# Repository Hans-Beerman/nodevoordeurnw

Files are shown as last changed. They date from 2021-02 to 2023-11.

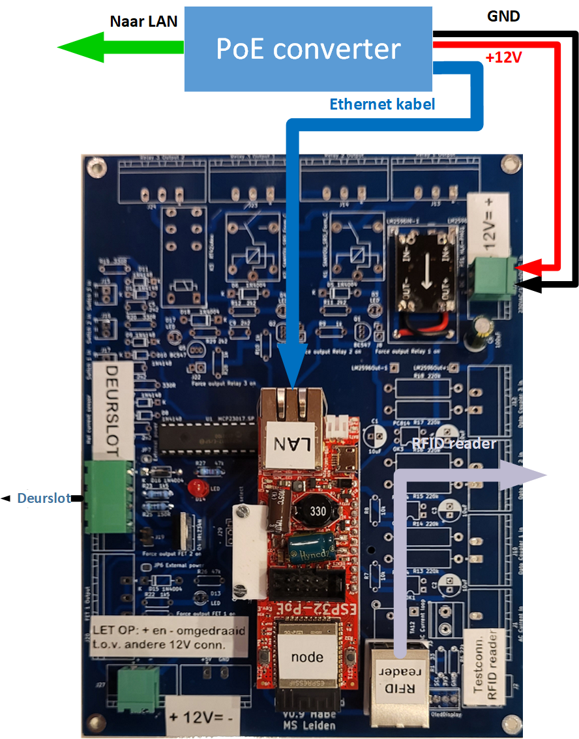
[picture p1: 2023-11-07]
Drawings/Aansluitschema print NodeVoordeur V0.9-2 20231104.png

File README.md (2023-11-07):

**NodeVoordeur**

NodeVoordeur is a node, used at the MakerSpace Leiden, to control the front door of the Makerspace. This repository has the following subdirs:

- **3D designs:**

The drawings of 3D parts, which are used on the PCB

- **Drawings:**

Schematic of the wiring between the different modules used

- **KiCad\_files:**

The design of the PCB used for the Node/Controller.

- **Photos:**

Some photos of the Node made.

- **PlatformIO\_Files:**

The source code for the Node. For the development of this software PlatformIO is used, an Extension on Visual Studio Code.

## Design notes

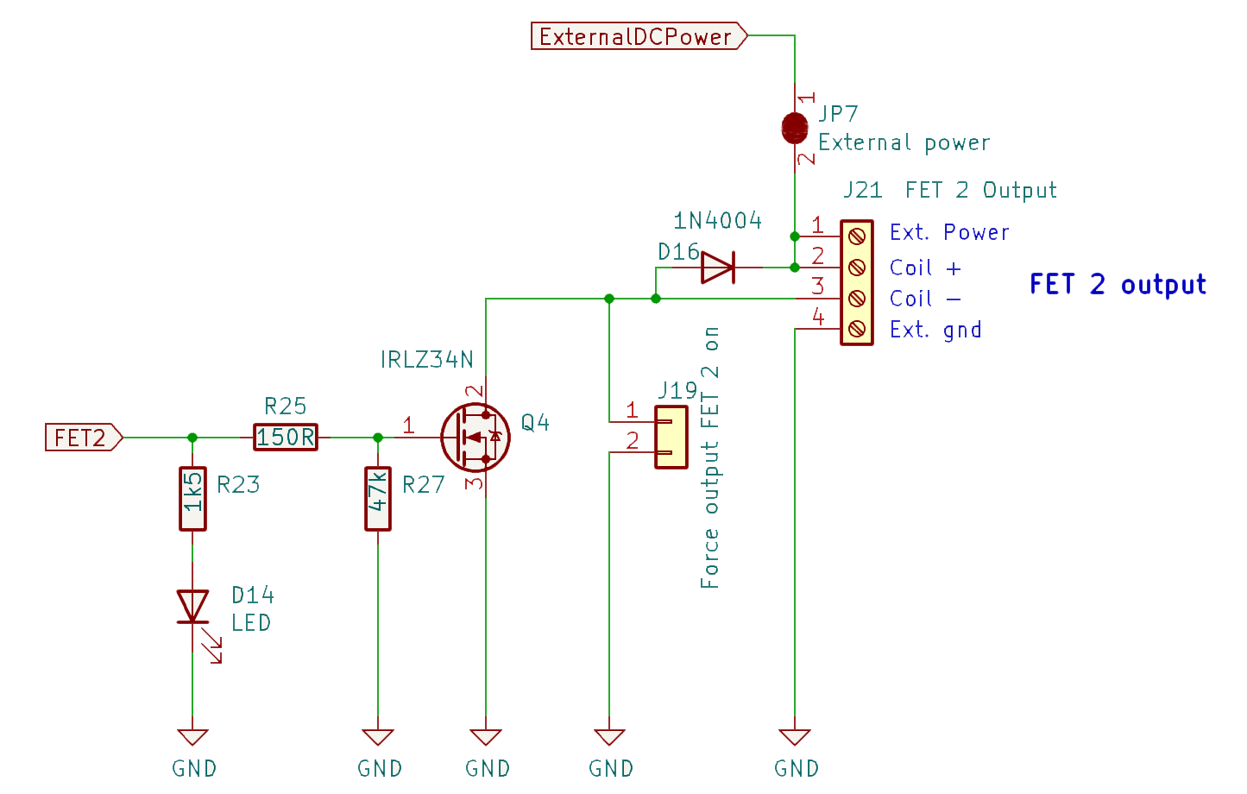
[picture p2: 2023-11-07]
Drawings/FET2 aansluiting deurslot.png

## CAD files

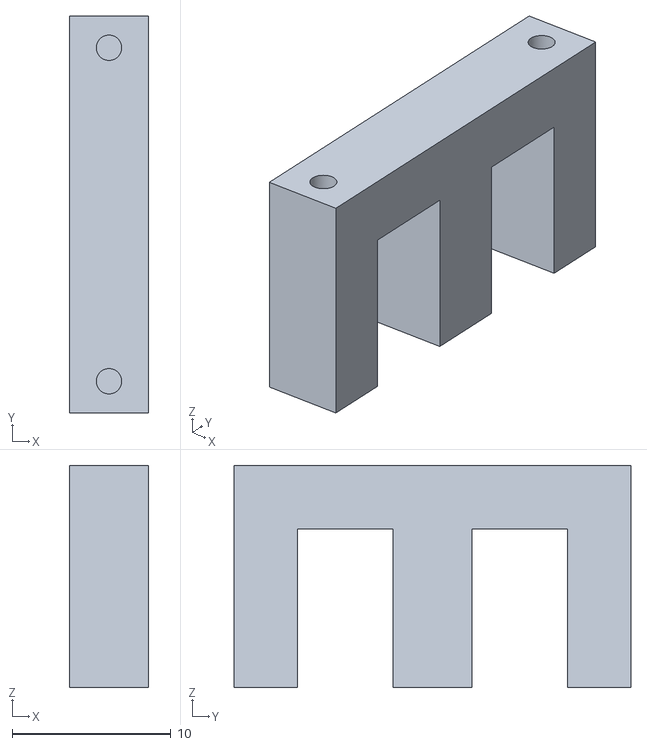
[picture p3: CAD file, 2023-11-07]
3D designs/stl files/Clip ESP32 onderkant.stl
5.00 x 25.0 x 14.0

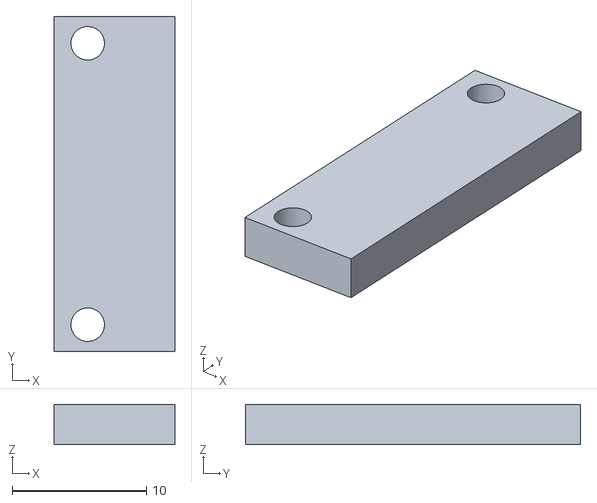
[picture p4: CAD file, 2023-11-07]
3D designs/stl files/Clip ESP32 bovenkant.stl
9.00 x 25.0 x 3.00

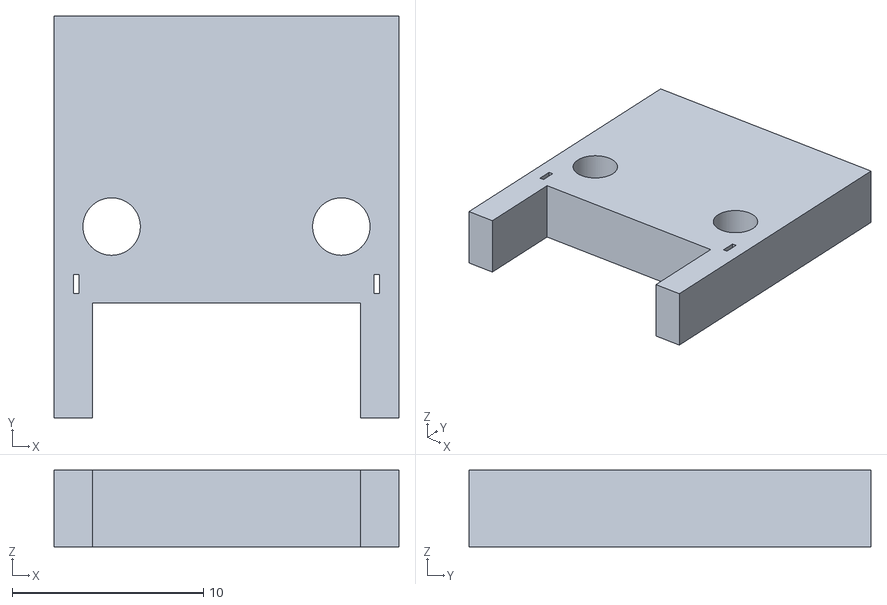
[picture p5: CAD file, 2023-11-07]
3D designs/stl files/Onderlegplaatje RJ45 female connector.stl
18.0 x 21.0 x 4.00

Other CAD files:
3D designs/Fusion 360 files/Clip ESP32 v4.f3d
3D designs/Fusion 360 files/Onderlegplaatje RJ45 female connector v1.f3d

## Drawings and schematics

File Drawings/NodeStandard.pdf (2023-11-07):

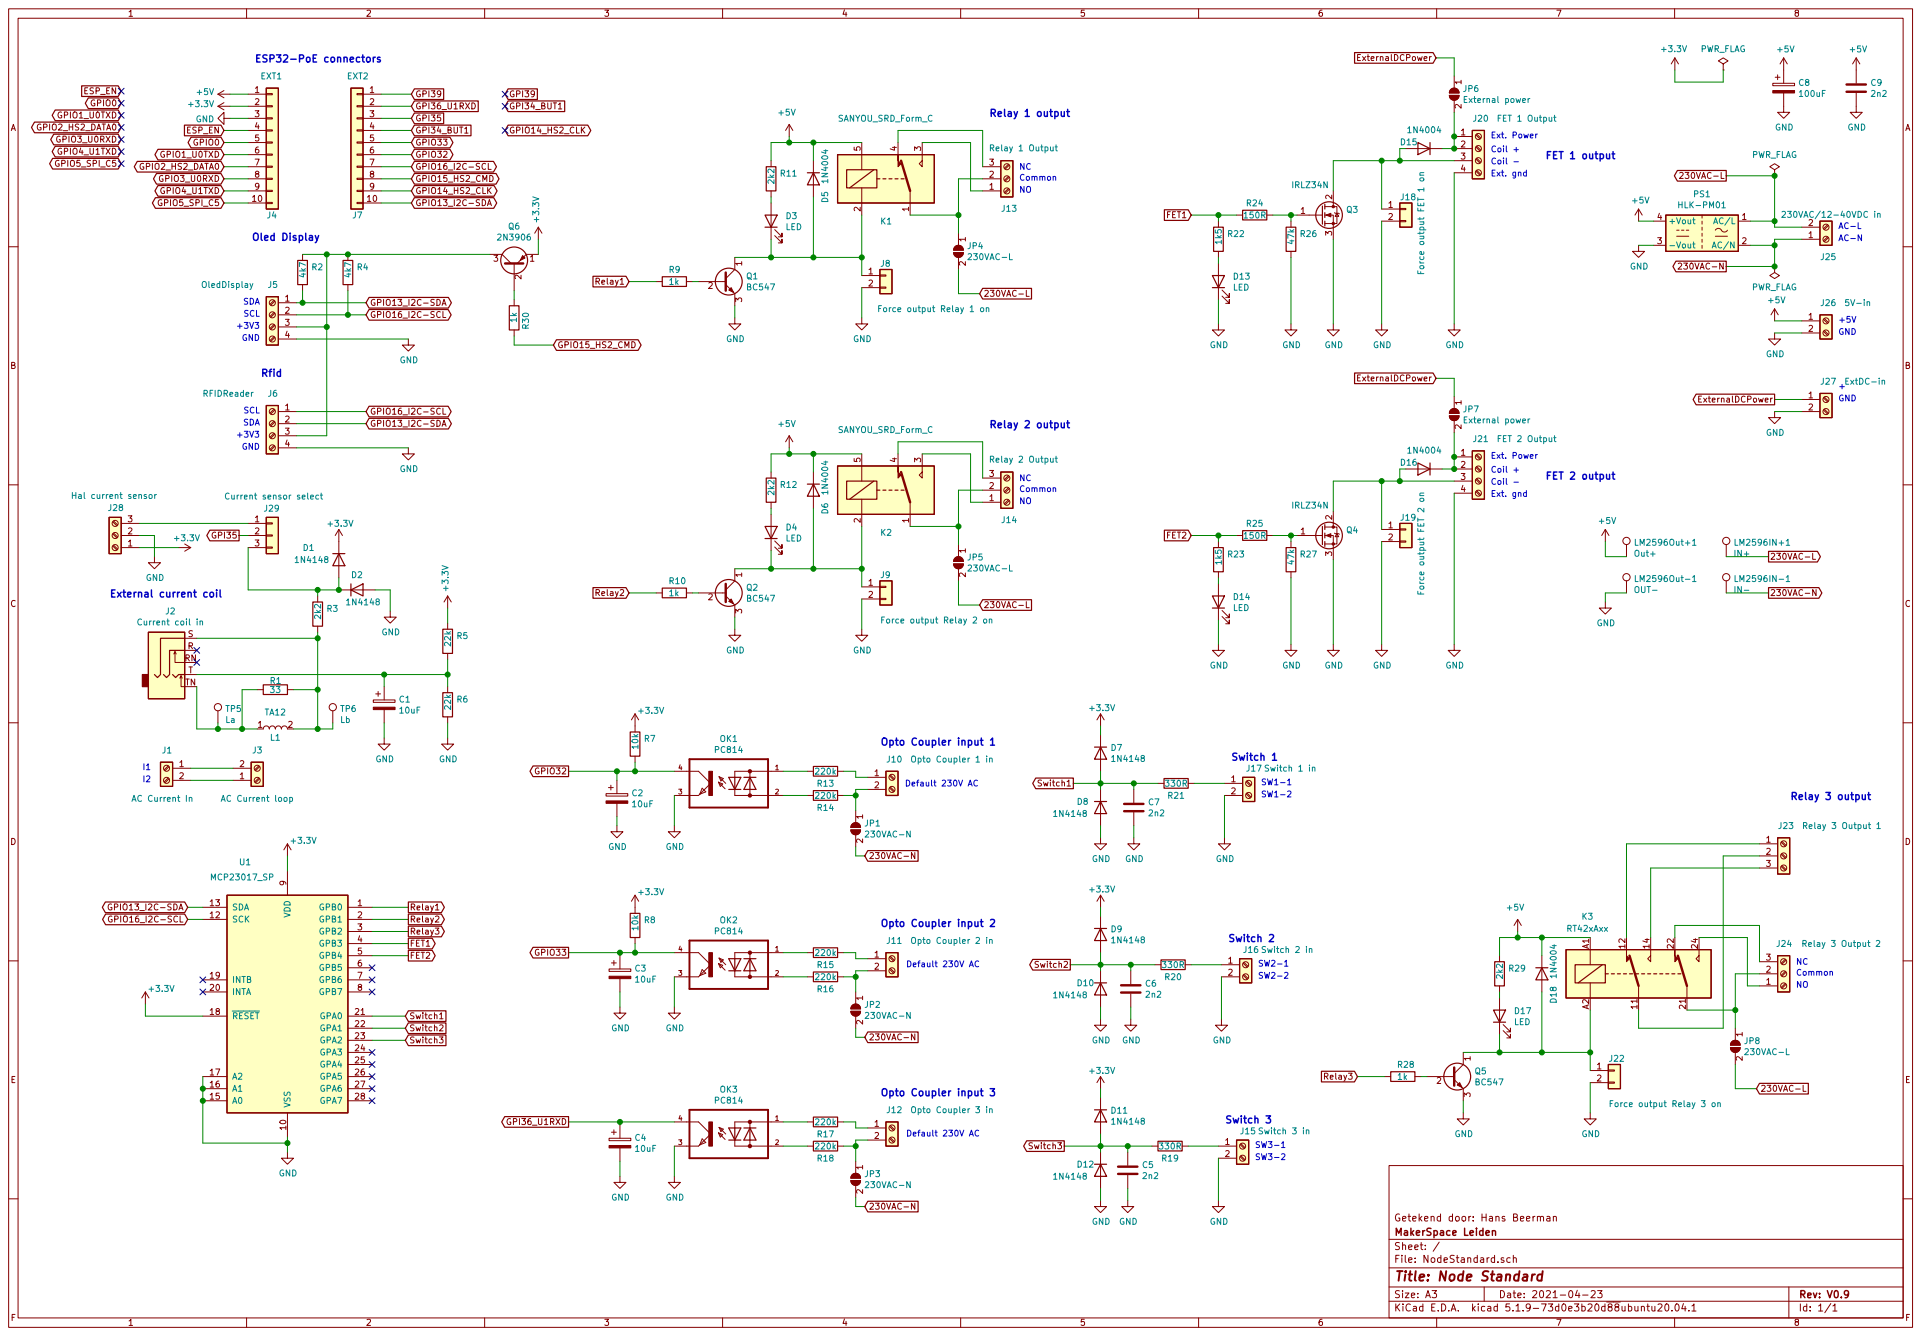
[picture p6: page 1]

1/2 J18 Force output FET 1 on D15

File: NodeStandard.sch Sheet: / MakerSpace Leiden Getekend door: Hans Beerman

Id: 1/1 Title: Node Standard

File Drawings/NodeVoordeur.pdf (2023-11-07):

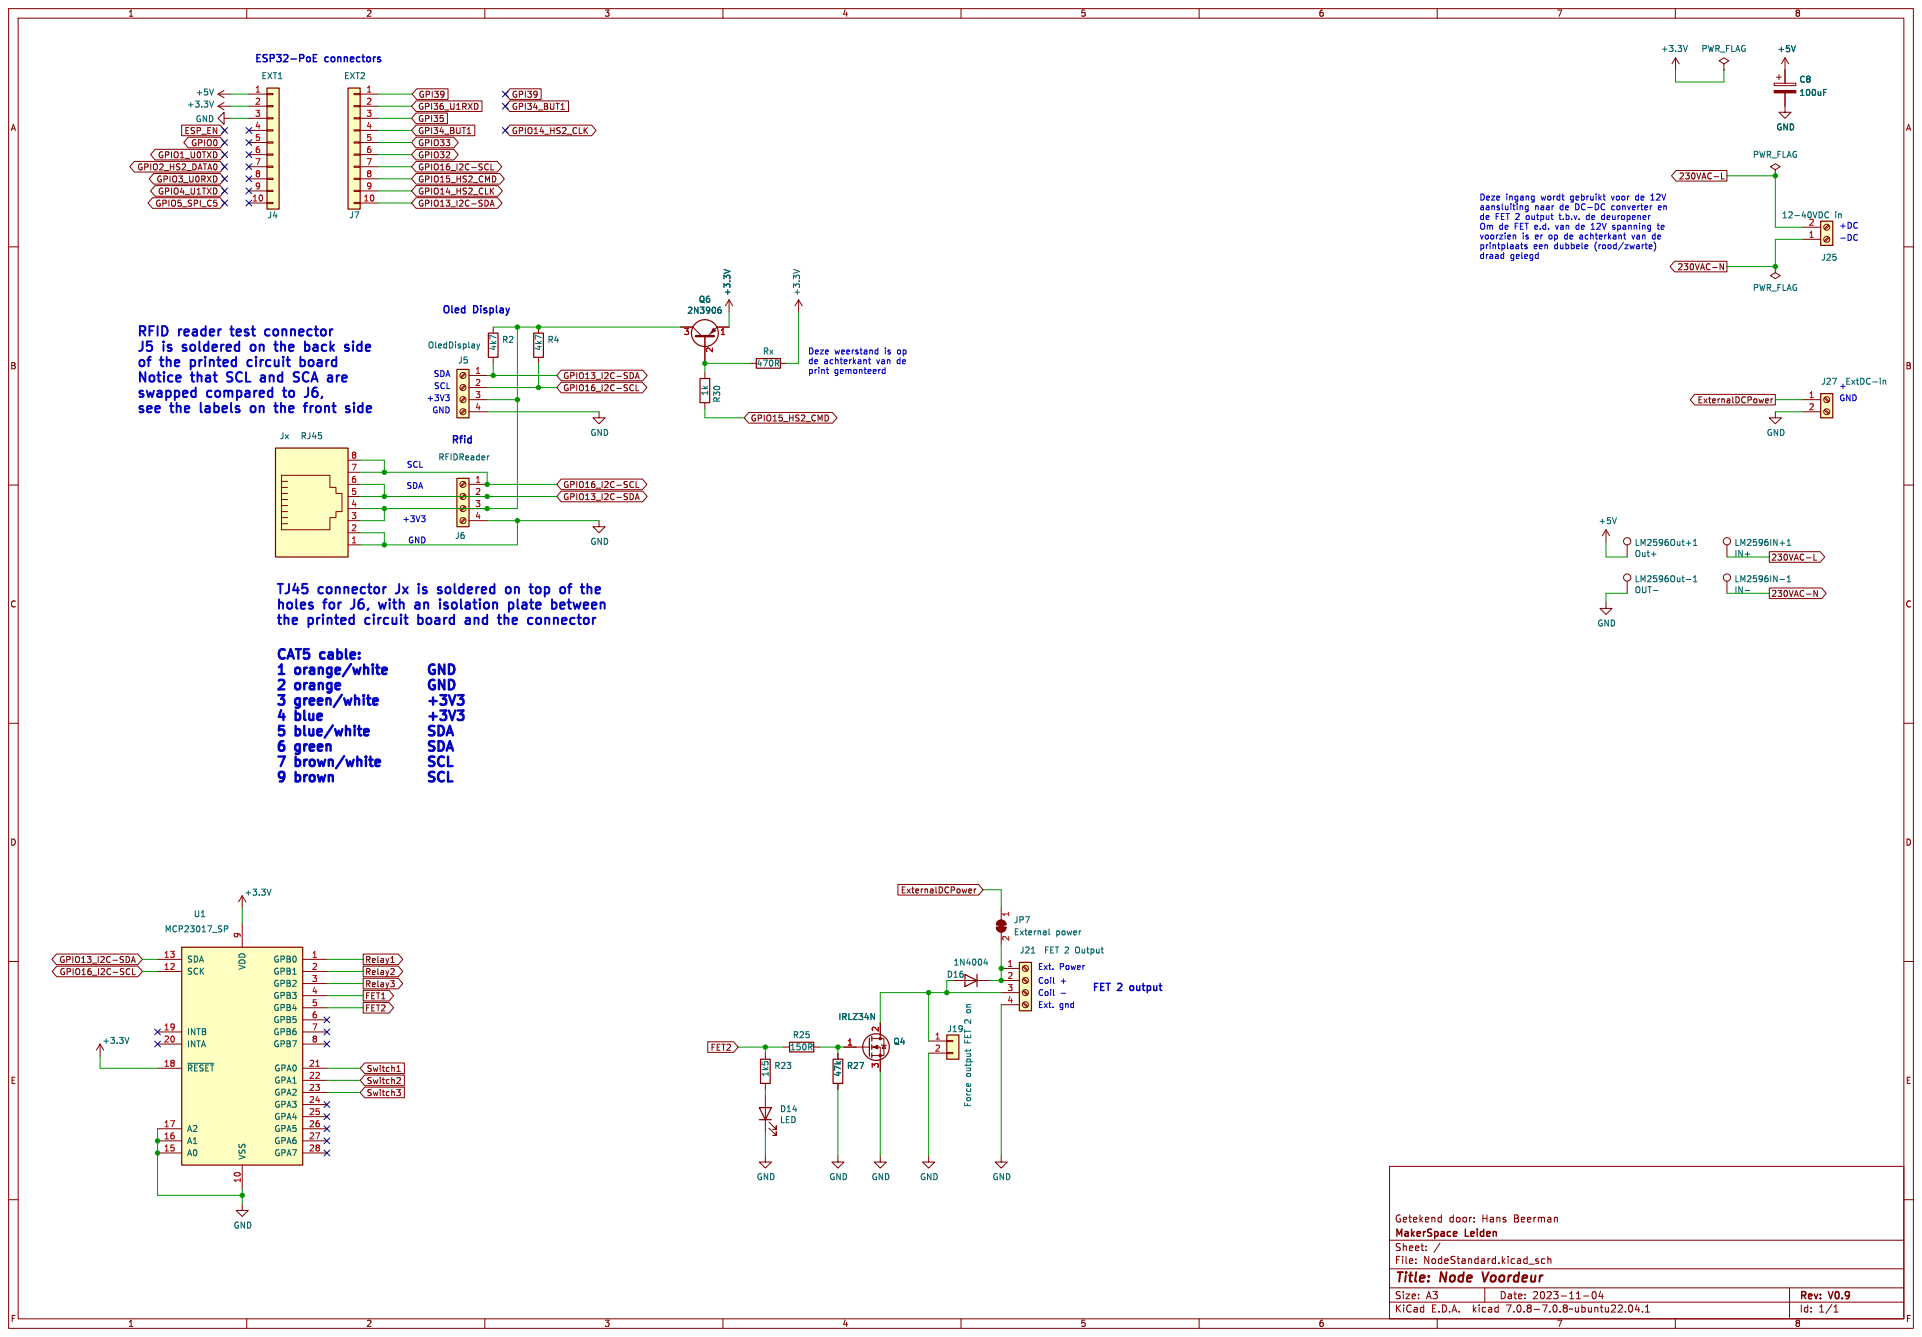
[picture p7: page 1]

J5 is soldered on the back side
of the printed circuit board
Notice that SCL and SCA are
swapped compared to J6, see the labels on the front side

TJ45 connector Jx is soldered on top of the
holes for J6, with an isolation plate between

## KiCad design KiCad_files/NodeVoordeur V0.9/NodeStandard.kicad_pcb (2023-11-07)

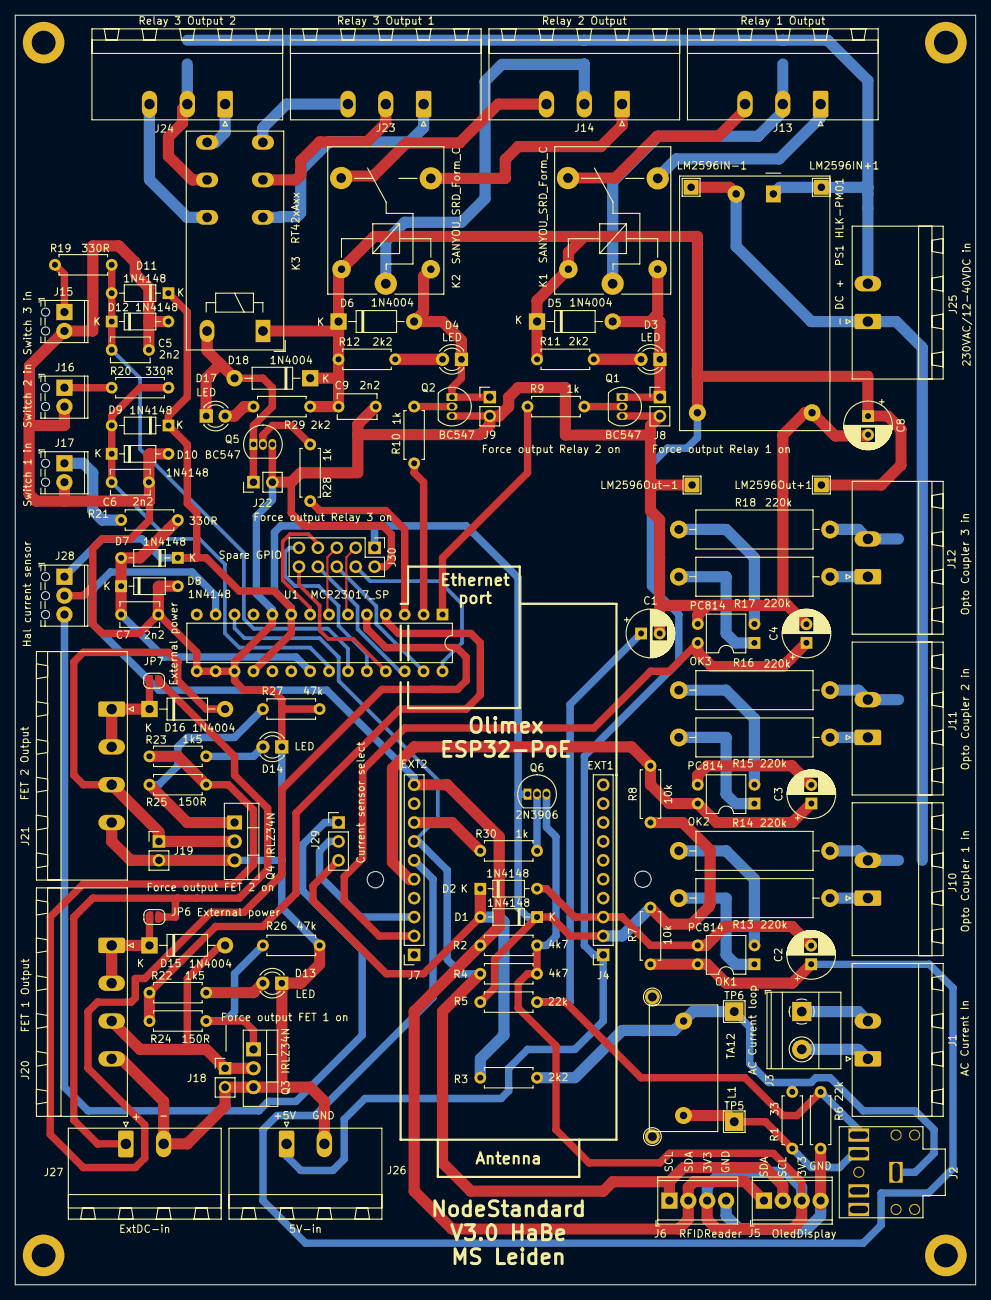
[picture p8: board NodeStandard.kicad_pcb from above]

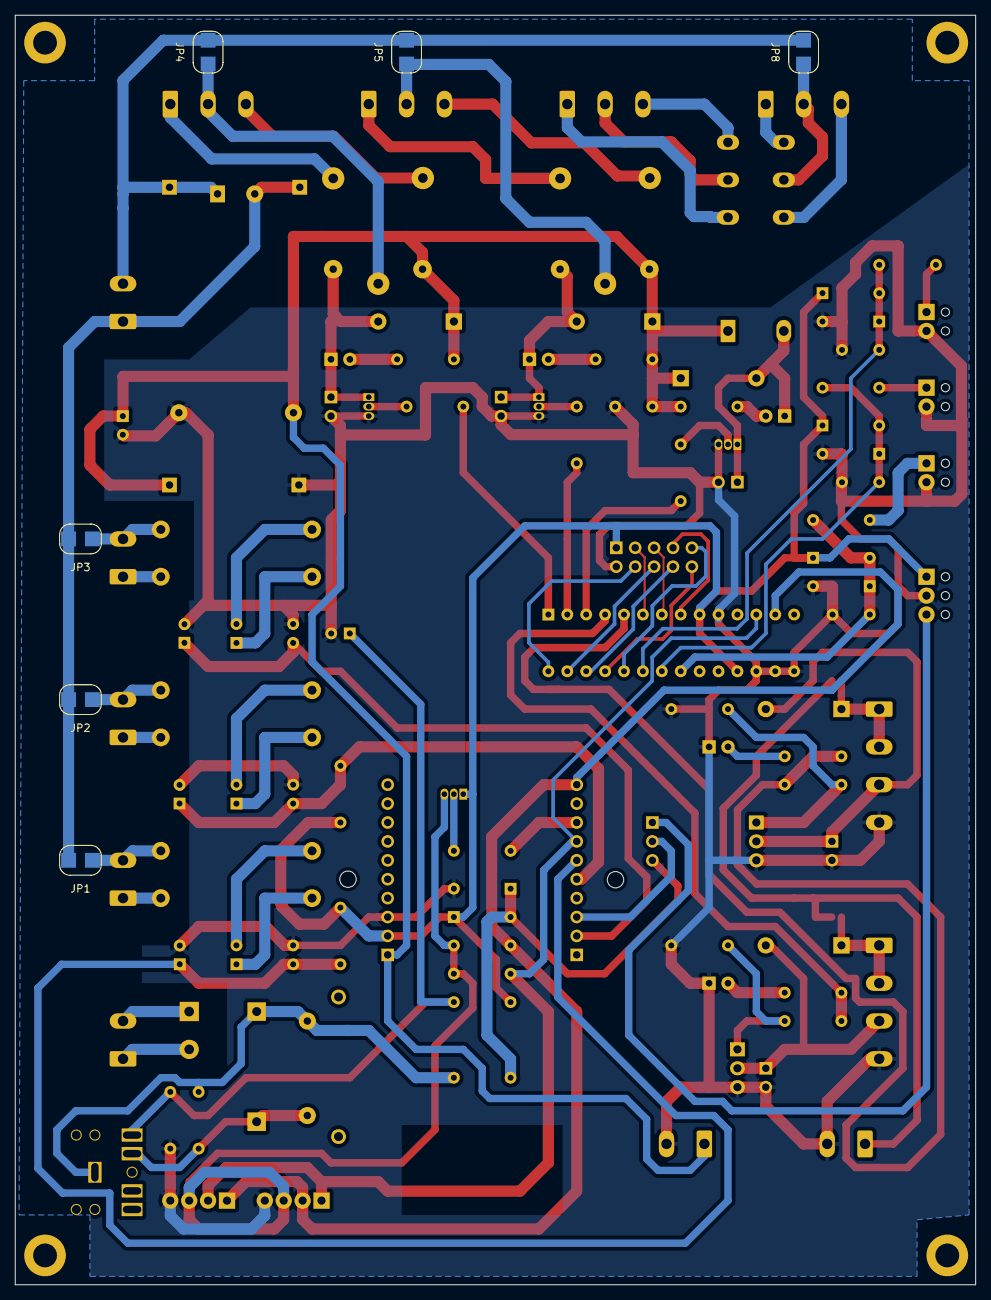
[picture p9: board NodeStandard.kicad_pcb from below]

Board: 2 copper layers, 129.0 x 170.6 mm, 116 parts (6 on the bottom side), 82 nets.

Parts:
C1, C2, C3, C4: 10uF; CP_Radial_D6.3mm_P2.50mm
C5, C6, C7, C9: 2n2; C_Disc_D5.1mm_W3.2mm_P5.00mm
C8: 100uF; CP_Radial_D6.3mm_P2.50mm
D1, D2, D7, D8, D9, D10, D11, D12: 1N4148; D_DO-35_SOD27_P7.62mm_Horizontal
D3, D4, D13, D14, D17: LED; LED_D3.0mm
D5, D6, D15, D16, D18: 1N4004; D_DO-41_SOD81_P10.16mm_Horizontal
J1: AC Current In; PhoenixContact_MSTB_2,5_2-GF-5,08_1x02_P5.08mm_Horizontal_T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
J2: Current coil in; Jack_3.5mm_CUI_FEMPM_Horizontal
J3: AC Current loop; TerminalBlock_Phoenix_MKDS-1,5-2-5.08_1x02_P5.08mm_Horizont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
J4: EXT1; PinSocket_1x10_P2.54mm_Vertical
J5: OledDisplay; TerminalBlock_Phoenix_MPT-0,5-4-2.54_1x04_P2.54mm_Horizontal
J6: RFIDReader; TerminalBlock_Phoenix_MPT-0,5-4-2.54_1x04_P2.54mm_Horizontal
J7: EXT2; PinSocket_1x10_P2.54mm_Vertical
J8: Force output Relay 1 on; PinHeader_1x02_P2.54mm_Vertical
J9: Force output Relay 2 on; PinHeader_1x02_P2.54mm_Vertical
J10: Opto Coupler 1 in; PhoenixContact_MSTB_2,5_2-GF-5,08_1x02_P5.08mm_Horizontal_T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
J11: Opto Coupler 2 in; PhoenixContact_MSTB_2,5_2-GF-5,08_1x02_P5.08mm_Horizontal_T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
J12: Opto Coupler 3 in; PhoenixContact_MSTB_2,5_2-GF-5,08_1x02_P5.08mm_Horizontal_T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
J13: Relay 1 Output; PhoenixContact_MSTB_2,5_3-GF-5,08_1x03_P5.08mm_Horizontal_T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
J14: Relay 2 Output; PhoenixContact_MSTB_2,5_3-GF-5,08_1x03_P5.08mm_Horizontal_T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
J15: Switch 3 in; TerminalBlock_Phoenix_MPT-0,5-2-2.54_1x02_P2.54mm_Horizontal
J16: Switch 2 in; TerminalBlock_Phoenix_MPT-0,5-2-2.54_1x02_P2.54mm_Horizontal
J17: Switch 1 in; TerminalBlock_Phoenix_MPT-0,5-2-2.54_1x02_P2.54mm_Horizontal
J18: Force output FET 1 on; PinHeader_1x02_P2.54mm_Vertical
J19: Force output FET 2 on; PinHeader_1x02_P2.54mm_Vertical
J20: FET 1 Output; PhoenixContact_MSTB_2,5_4-GF-5,08_1x04_P5.08mm_Horizontal_T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
J21: FET 2 Output; PhoenixContact_MSTB_2,5_4-GF-5,08_1x04_P5.08mm_Horizontal_T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
J22: Force output Relay 3 on; PinHeader_1x02_P2.54mm_Vertical
J23: Relay 3 Output 1; PhoenixContact_MSTB_2,5_3-GF-5,08_1x03_P5.08mm_Horizontal_T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
J24: Relay 3 Output 2; PhoenixContact_MSTB_2,5_3-GF-5,08_1x03_P5.08mm_Horizontal_T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
J25: 230VAC/12-40VDC in; PhoenixContact_MSTB_2,5_2-GF-5,08_1x02_P5.08mm_Horizontal_T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
J26: 5V-in; PhoenixContact_MSTB_2,5_2-GF-5,08_1x02_P5.08mm_Horizontal_T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
J27: ExtDC-in; PhoenixContact_MSTB_2,5_2-GF-5,08_1x02_P5.08mm_Horizontal_T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
J28: Hal current sensor; TerminalBlock_Phoenix_MPT-0,5-3-2.54_1x03_P2.54mm_Horizontal
J29: Current sensor select; PinHeader_1x03_P2.54mm_Vertical
J30: Spare GPIO; PinHeader_2x05_P2.54mm_Vertical
JP1, JP2, JP3: 230VAC-N; SolderJumper-2_P3mm_Open_RoundedPad
JP4, JP5, JP8: 230VAC-L; SolderJumper-2_P3mm_Open_RoundedPad
JP6, JP7: External power; SolderJumper-2_P1.3mm_Open_RoundedPad1.0x1.5mm
K1, K2: SANYOU_SRD_Form_C; Relay_SPDT_SANYOU_SRD_Series_Form_C
K3: RT42xAxx; Relay_DPDT_Schrack-RT2-FormC_RM5mm
L1: TA12; TA12-100
LM2596IN+1: IN+; TestPoint_THTPad_2.0x2.0mm_Drill1.0mm
LM2596IN-1: IN-; TestPoint_THTPad_2.0x2.0mm_Drill1.0mm
LM2596Out+1: Out+; TestPoint_THTPad_2.0x2.0mm_Drill1.0mm
LM2596Out-1: OUT-; TestPoint_THTPad_2.0x2.0mm_Drill1.0mm
OK1, OK2, OK3: PC814; DIP-4_W7.62mm
PS1: HLK-PM01; Converter_ACDC_HiLink_HLK-PMxx
Q1, Q2, Q5: BC547; TO-92_Inline
Q3, Q4: IRLZ34N; TO-220-3_Vertical
Q6: 2N3906; TO-92_Inline
R1: 33; R_Axial_DIN0207_L6.3mm_D2.5mm_P7.62mm_Horizontal
R2, R4: 4k7; R_Axial_DIN0207_L6.3mm_D2.5mm_P7.62mm_Horizontal
R3, R11, R12, R29: 2k2; R_Axial_DIN0207_L6.3mm_D2.5mm_P7.62mm_Horizontal
R5, R6: 22k; R_Axial_DIN0207_L6.3mm_D2.5mm_P7.62mm_Horizontal
R7, R8: 10k; R_Axial_DIN0207_L6.3mm_D2.5mm_P7.62mm_Horizontal
R9, R10, R28, R30: 1k; R_Axial_DIN0207_L6.3mm_D2.5mm_P7.62mm_Horizontal
R13, R14, R15, R16, R17, R18: 220k; R_Axial_DIN0516_L15.5mm_D5.0mm_P20.32mm_Horizontal
R19, R20, R21: 330R; R_Axial_DIN0207_L6.3mm_D2.5mm_P7.62mm_Horizontal
R22, R23: 1k5; R_Axial_DIN0207_L6.3mm_D2.5mm_P7.62mm_Horizontal
R24, R25: 150R; R_Axial_DIN0207_L6.3mm_D2.5mm_P7.62mm_Horizontal
R26, R27: 47k; R_Axial_DIN0207_L6.3mm_D2.5mm_P7.62mm_Horizontal
TP5: La; TestPoint_THTPad_2.5x2.5mm_Drill1.2mm
TP6: Lb; TestPoint_THTPad_2.5x2.5mm_Drill1.2mm
U1: MCP23017_SP; DIP-28_W7.62mm

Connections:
230VAC-L: J25.2, JP4.2 (B), JP5.2 (B), JP8.2 (B), LM2596IN+1.1, PS1.1 (AC/L)
230VAC-N: J25.1, JP1.2 (B), JP2.2 (B), JP3.2 (B), LM2596IN-1.1, PS1.2 (AC/N)
+3V3: D1.1 (K), D7.1 (K), D9.1 (K), D11.1 (K), J4.2, J28.1, J30.1, Q6.1 (E), R5.1, R7.1, R8.1, U1.9 (VDD), U1.18 (~RESET)
+5V: C8.1, C9.1, D5.1 (K), D6.1 (K), D18.1 (K), J4.1, J26.1, K1.5, K2.5, K3.A1, LM2596Out+1.1, PS1.4 (+Vout), R11.1, R12.1, R29.1
ExternalDCPower: J27.1, JP6.1 (A), JP7.1 (A)
FET1: R22.1, R24.2, U1.4 (GPB3)
FET2: R23.1, R25.2, U1.5 (GPB4)
GND: C1.2, C2.2, C3.2, C4.2, C5.2, C6.2, C7.2, C8.2, C9.2, D2.2 (A), D8.2 (A), D10.2 (A), D12.2 (A), D13.1 (K), D14.1 (K), J4.3, J5.4, J6.4, J8.2, J9.2, J15.2, J16.2, J17.2, J18.2, J19.2, J20.4, J21.4, J22.2, J26.2, J27.2, J28.2, J30.2, LM2596Out-1.1, OK1.3 (E), OK2.3 (E), OK3.3 (E), PS1.3 (-Vout), Q1.3 (E), Q2.3 (E), Q3.3 (S), Q4.3 (S), Q5.3 (E), R6.2, R26.2, R27.2, U1.10 (VSS), U1.15 (A0), U1.16 (A1), U1.17 (A2)
GPI35: J7.3, J29.2
GPI36_U1RXD: C4.1, J7.2, OK3.4 (C)
GPIO13_I2C-SDA: J5.1, J6.2, J7.10, R2.2, U1.13 (SDA)
GPIO15_HS2_CMD: J7.8, R30.1
GPIO16_I2C-SCL: J5.2, J6.1, J7.7, R4.2, U1.12 (SCK)
GPIO32: C2.1, J7.6, OK1.4 (C), R7.2
GPIO33: C3.1, J7.5, OK2.4 (C), R8.2
unnamed: C1.1, J2.T, R5.2, R6.1
unnamed: D1.2 (A), D2.1 (K), J29.3, R3.1
unnamed: D3.1 (K), D5.2 (A), J8.1, K1.2, Q1.1 (C)
unnamed: D3.2 (A), R11.2
unnamed: D4.1 (K), D6.2 (A), J9.1, K2.2, Q2.1 (C)
unnamed: D4.2 (A), R12.2
unnamed: D13.2 (A), R22.2
unnamed: D14.2 (A), R23.2
unnamed: D15.1 (K), J20.1, J20.2, JP6.2 (B)
unnamed: D15.2 (A), J18.1, J20.3, Q3.2 (D)
unnamed: D16.1 (K), J21.1, J21.2, JP7.2 (B)
unnamed: D16.2 (A), J19.1, J21.3, Q4.2 (D)
unnamed: D17.1 (K), D18.2 (A), J22.1, K3.A2, Q5.1 (C)
unnamed: D17.2 (A), R29.2
unnamed: J1.1, J3.2
unnamed: J1.2, J3.1
unnamed: J2.S, L1.2, R1.1, R3.2, TP6.1
unnamed: J2.TN, L1.1, R1.2, TP5.1
unnamed: J5.3, J6.3, Q6.3 (C), R2.1, R4.1
unnamed: J10.1, R13.1
unnamed: J10.2, JP1.1 (A), R14.1
unnamed: J11.1, R15.1
unnamed: J11.2, JP2.1 (A), R16.1
unnamed: J12.1, R17.1
unnamed: J12.2, JP3.1 (A), R18.1
unnamed: J13.1, K1.3
unnamed: J13.2, JP4.1 (A), K1.1
unnamed: J13.3, K1.4
unnamed: J14.1, K2.3
unnamed: J14.2, JP5.1 (A), K2.1
unnamed: J14.3, K2.4
unnamed: J15.1, R19.1
unnamed: J16.1, R20.1
unnamed: J17.1, R21.1
unnamed: J23.1, K3.12
unnamed: J23.2, K3.11
unnamed: J23.3, K3.14
unnamed: J24.1, K3.24
unnamed: J24.2, JP8.1 (A), K3.21
unnamed: J24.3, K3.22
unnamed: J28.3, J29.1
unnamed: J30.3, U1.6 (GPB5)
unnamed: J30.4, U1.28 (GPA7)
unnamed: J30.5, U1.7 (GPB6)
unnamed: J30.6, U1.27 (GPA6)
unnamed: J30.7, U1.8 (GPB7)
unnamed: J30.8, U1.26 (GPA5)
unnamed: J30.9, U1.24 (GPA3)
unnamed: J30.10, U1.25 (GPA4)
unnamed: OK1.1 (AC1), R13.2
unnamed: OK1.2 (AC2), R14.2
unnamed: OK2.1 (AC1), R15.2
unnamed: OK2.2 (AC2), R16.2
unnamed: OK3.1 (AC1), R17.2
unnamed: OK3.2 (AC2), R18.2
unnamed: Q1.2 (B), R9.1
unnamed: Q2.2 (B), R10.1
unnamed: Q3.1 (G), R24.1, R26.1
unnamed: Q4.1 (G), R25.1, R27.1
unnamed: Q5.2 (B), R28.1
unnamed: Q6.2 (B), R30.2
Relay1: R9.2, U1.1 (GPB0)
Relay2: R10.2, U1.2 (GPB1)
Relay3: R28.2, U1.3 (GPB2)
Switch1: C7.1, D7.2 (A), D8.1 (K), R21.2, U1.21 (GPA0)
Switch2: C6.1, D9.2 (A), D10.1 (K), R20.2, U1.22 (GPA1)
Switch3: C5.1, D11.2 (A), D12.1 (K), R19.2, U1.23 (GPA2)

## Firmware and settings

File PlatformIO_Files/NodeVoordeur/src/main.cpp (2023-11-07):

/*
   Copyright 2015-2018 Dirk-Willem van Gulik <dirkx@webweaving.org>
   Copyright 2020-2021 Hans Beerman <hans.beerman@xs4all.nl>
                       Stichting Makerspace Leiden, the Netherlands.

   Licensed under the Apache License, Version 2.0 (the "License");
   you may not use this file except in compliance with the License.
   You may obtain a copy of the License at

       http://www.apache.org/licenses/LICENSE-2.0

   Unless required by applicable law or agreed to in writing, software
   distributed under the License is distributed on an "AS IS" BASIS,
   WITHOUT WARRANTIES OR CONDITIONS OF ANY KIND, either express or implied.
   See the License for the specific language governing permissions and
   limitations under the License.
*/

#ifndef ESP32
#error "The NodeVoordeur uses an ESP32 based board (Olimex ESP32-PoE)!"
#endif

// An Olimex ESP32-PoE is used (default is POESP board (Aart board))
#define ESP32_PoE


// for debugging
// see DEBUGIT flag in platformio.ini

// i2C params
// Defined in platformio.ini:
// RFID_SDA_PIN=13
// RFID_SCL_PIN=16

#include <Arduino.h>
#include <PowerNodeV11.h>
#include <ACNode.h>
#include <RFID.h>   // NFC version
#include <SIG2.h>
#include <Cache.h>
#include <EEPROM.h>

#include "MCP23017IO.h"

#include ".passwd.h"
/* If using WiFi instead of a fixed ethernet connection, and/or OTA:

Add Passwd.h to the NodeOven/src directoy containing the following information

#pragma once

#define WIFI_NETWORK "YOUR_SSID"
#define WIFI_PASSWD "YOUR_PASSWD"

#define OTA_PASSWD "YOUR_OTA_PASSWD"
*/

#define MACHINE "voordeurnw"

// See https://mailman.makerspaceleiden.nl/mailman/private/deelnemers/2019-February/019837.html

// Introduced by alex - 2020-01-8

// Clear EEProm + Cache button
// Press BUT1 on Olimex ESP32 PoE module before (re)boot of node
// keep BUT1 pressed for at least 5 s
// After the release of BUT1 node will restart with empty EEProm and empty cache
#define CLEAR_EEPROM_AND_CACHE_BUTTON           (34)
#define CLEAR_EEPROM_AND_CACHE_BUTTON_PRESSED   (LOW)
#define MAX_WAIT_TIME_BUTTON_PRESSED            (4000)  // in ms

#define DOOR_OPEN_TIME                          (5) // in s
#define CHECK_NFC_READER_AVAILABLE_TIME_WINDOW  (10000) // in ms  
#define GPIOPORT_I2C_RECOVER_RELAY              (15)       


#ifdef WIFI_NETWORK
ACNode node = ACNode(MACHINE, WIFI_NETWORK, WIFI_PASSWD);
#else
ACNode node = ACNode(MACHINE);
#endif

#define USE_CACHE_FOR_TAGS true
#define USE_NFC_RFID_CARD true

RFID reader = RFID(USE_CACHE_FOR_TAGS, USE_NFC_RFID_CARD); // use tags are stored in cache, to allow access in case the MQTT server is down; also use NFC RFID card

MqttLogStream mqttlogStream = MqttLogStream();
TelnetSerialStream telnetSerialStream = TelnetSerialStream();

#ifdef OTA_PASSWD
OTA ota = OTA(OTA_PASSWD);
#endif


// LED aartLed = LED(SYSTEM_LED);    // defaults to the aartLed - otherwise specify a GPIO.

typedef enum {
  BOOTING, OUTOFORDER,      // device not functional.
  REBOOT,                   // forcefull reboot
  TRANSIENTERROR,           // hopefully goes away level error
  NOCONN,                   // sort of fairly hopless (though we can cache RFIDs!)
  WAITINGFORCARD,           // waiting for card.
  CHECKINGCARD,
  CLEARSTATUS,
  APPROVED,
  REJECTED,
  LOCKOPEN,
  LOCKCLOSED,
} machinestates_t;


#define NEVER (0)

struct {
  const char * label;                   // name of this state
  LED::led_state_t ledState;            // flashing pattern for the aartLED. Zie ook https://wiki.makerspaceleiden.nl/mediawiki/index.php/Powernode_1.1.
  time_t maxTimeInMilliSeconds;         // how long we can stay in this state before we timeout.
  machinestates_t failStateOnTimeout;   // what state we transition to on timeout.
  unsigned long timeInState;
  unsigned long timeoutTransitions;
  unsigned long autoReportCycle;
} state[LOCKCLOSED + 1] =
{
  { "Booting",                LED::LED_ERROR,                   120 * 1000, REBOOT,         0 },
  { "Out of order",           LED::LED_ERROR,                   120 * 1000, REBOOT,         5 * 60 * 1000 },
  { "Rebooting",              LED::LED_ERROR,                   120 * 1000, REBOOT,         0 },
  { "Transient Error",        LED::LED_ERROR,                     5 * 1000, WAITINGFORCARD, 5 * 60 * 1000 },
  { "No network",             LED::LED_FLASH,                        NEVER, NOCONN,         0 },
  { "Waiting for card",       LED::LED_IDLE,                         NEVER, WAITINGFORCARD, 0 },
  { "Checking card",          LED::LED_PENDING,                   5 * 1000, REJECTED,       0 },
  { "Clear status",           LED::LED_PENDING,                      NEVER, WAITINGFORCARD, 0 },
  { "Approved card",          LED::LED_PENDING,                  60 * 1000, CLEARSTATUS,    0 },
  { "Rejected",               LED::LED_ERROR,                     5 * 1000, CLEARSTATUS,    0 },
  { "Door lock is open",      LED::LED_ON,           DOOR_OPEN_TIME * 1000, LOCKCLOSED,     0 },
  { "Door lock is closed",    LED::LED_ON,                           NEVER, WAITINGFORCARD, 0 },
};

unsigned long laststatechange = 0, lastReport = 0;
static machinestates_t laststate = OUTOFORDER;
machinestates_t machinestate = BOOTING;

// to handle onconnect only once (only after reboot)
static bool firstOnConnectTime = true;

char reportStr[128];

unsigned long approvedCards = 0;
unsigned long rejectedCards = 0;

// For storing the local IP address of the node
IPAddress theLocalIPAddress;

unsigned long lastCheckNFCReaderTime = 0;

void checkClearEEPromAndCacheButtonPressed(void) {
  unsigned long ButtonPressedTime;
  unsigned long currentSecs;
  unsigned long prevSecs;
  bool firstTime = true;

  // check CLEAR_EEPROM_AND_CACHE_BUTTON pressed
  pinMode(CLEAR_EEPROM_AND_CACHE_BUTTON, INPUT);
  // check if button is pressed for at least 3 s
  Log.println("Checking if the button is pressed for clearing EEProm and cache");
  ButtonPressedTime = millis();  
  prevSecs = MAX_WAIT_TIME_BUTTON_PRESSED / 1000;
  Log.print(prevSecs);
  Log.print(" s");
  while (digitalRead(CLEAR_EEPROM_AND_CACHE_BUTTON) == CLEAR_EEPROM_AND_CACHE_BUTTON_PRESSED) {
    if ((millis() - ButtonPressedTime) >= MAX_WAIT_TIME_BUTTON_PRESSED) {
      if (firstTime == true) {
        Log.print("\rPlease release button");
        firstTime = false;
      }
    } else {
      currentSecs = (MAX_WAIT_TIME_BUTTON_PRESSED - millis()) / 1000;
      if ((currentSecs != prevSecs) && (currentSecs >= 0)) {
        Log.print("\r");
        Log.print(currentSecs);
        Log.print(" s");
        prevSecs = currentSecs;
      }
    }
  }
  if (millis() - ButtonPressedTime >= MAX_WAIT_TIME_BUTTON_PRESSED) {
    Log.print("\rButton for clearing EEProm and cache was pressed for more than ");
    Log.print(MAX_WAIT_TIME_BUTTON_PRESSED / 1000);
    Log.println(" s, EEProm and Cache will be cleared!");
    // Clear EEPROM
    EEPROM.begin(1024);
    wipe_eeprom();
    Log.println("EEProm cleared!");
    // Clear cache
    prepareCache(true);
    Log.println("Cache cleared!");
    // wait until button is released, than reboot
    while (digitalRead(CLEAR_EEPROM_AND_CACHE_BUTTON) == CLEAR_EEPROM_AND_CACHE_BUTTON_PRESSED) {
      // do nothing here
    }
    Log.println("Node will be restarted");
    // restart node
    ESP.restart();
  } else {
    Log.println("\rButton was not (or not long enough) pressed to clear EEProm and cache");
  }
}


void checkNFCReaderAvailable() {
  if (USE_NFC_RFID_CARD) {
    if (!reader.CheckPN53xBoardAvailable()) {
      // Error in communuication with RFID reader, try resetting communication
      pinMode(RFID_CLK_PIN, OUTPUT);
      digitalWrite(RFID_CLK_PIN, 0);
      pinMode(RFID_SDA_PIN, OUTPUT);
      digitalWrite(RFID_SDA_PIN, 0);

      pinMode(GPIOPORT_I2C_RECOVER_RELAY, OUTPUT);
      digitalWrite(GPIOPORT_I2C_RECOVER_RELAY, 1);

      delay(500);

      pinMode(GPIOPORT_I2C_RECOVER_RELAY, OUTPUT);
      digitalWrite(GPIOPORT_I2C_RECOVER_RELAY, 0);
      reader.begin();
    }
  }
}

void setup() {
  Serial.begin(115200);
  Serial.println("\n\n\n");
  Serial.println("Booted: " __FILE__ " " __DATE__ " " __TIME__ );

  // for recovery relay I2C
  pinMode(GPIOPORT_I2C_RECOVER_RELAY, OUTPUT);
  digitalWrite(GPIOPORT_I2C_RECOVER_RELAY, 0);

  setup_MCP23017();

  checkClearEEPromAndCacheButtonPressed();

  node.set_mqtt_prefix("ac");
  node.set_master("master");

  node.onConnect([]() {
    Log.println("Connected");
    if (firstOnConnectTime == true) {
      firstOnConnectTime = false;
      machinestate = WAITINGFORCARD;
    }
  });
  node.onDisconnect([]() {
    Log.println("Disconnected");
  });
  node.onError([](acnode_error_t err) {
    Log.printf("Error %d\n", err);
    machinestate = WAITINGFORCARD;
  });
  node.onApproval([](const char * machine) {
    Debug.print("Got approve for machine: ");
    Debug.println(machine);
    if ((machinestate == WAITINGFORCARD) || (machinestate == CHECKINGCARD)) {
      approvedCards++;
      openDoor();
      machinestate = APPROVED;
      Log.println("User is approved and the door is opened");
    }
  });
  node.onDenied([](const char * machine) {
    Debug.println("Got denied");
    if (machinestate > REJECTED) {
      Debug.println("Denied ingnored, door is already open");
    } else {
      machinestate = REJECTED;
      rejectedCards++;
    }
  });

  node.set_report_period(20 * 1000);
  node.onReport([](JsonObject  & report) {
    report["state"] = state[machinestate].label;

#ifdef OTA_PASSWD
    report["ota"] = true;
#else
    report["ota"] = false;
#endif
    snprintf(reportStr, sizeof(reportStr), "%lu", approvedCards);
    report["approved cards"] = reportStr;
    snprintf(reportStr, sizeof(reportStr), "%lu", rejectedCards);
    report["rejected cards"] = reportStr;

    theLocalIPAddress = node.localIP();
    report["IP_address"] = theLocalIPAddress.toString();
  });

  reader.onSwipe([](const char * tag) -> ACBase::cmd_result_t {
    // avoid swithing messing with the swipe process
    if (machinestate > CHECKINGCARD) {
      Debug.printf("Ignoring a normal swipe - as we're still in some open process.");
      checkNFCReaderAvailable();
      return ACBase::CMD_CLAIMED;
    }

    // We'r declining so that the core library handle sending
    // an approval request, keep state, and so on.
    //
    Debug.printf("Detected a normal swipe.\n");
    checkNFCReaderAvailable();
    machinestate = CHECKINGCARD;
  //  buzz = CHECK;
    return ACBase::CMD_DECLINE;
  });


  // This reports things such as FW version of the card; which can 'wedge' it. So we
  // disable it unless we absolutely positively need that information.
  //
  reader.set_debug(false);
  node.addHandler(&reader);
 
#ifdef OTA_PASSWD
  node.addHandler(&ota);
#endif

  Log.addPrintStream(std::make_shared<MqttLogStream>(mqttlogStream));

  auto t = std::make_shared<TelnetSerialStream>(telnetSerialStream);
  Log.addPrintStream(t);
  Debug.addPrintStream(t);

  // node.set_debug(true);
  // node.set_debugAlive(true);

// if Olimex ESP32-PoE board is used
#ifdef ESP32_PoE  
  node.begin(BOARD_OLIMEX);
#endif

// if default, board (POESP, board Aart) is used
#ifndef ESP32_PoE
  node.begin();
#endif
  Log.println("Booted: " __FILE__ " " __DATE__ " " __TIME__ );
}

unsigned long now;

void loop() {
  node.loop();

  if (USE_NFC_RFID_CARD) {
    now = millis();
    if ((now - lastCheckNFCReaderTime) > CHECK_NFC_READER_AVAILABLE_TIME_WINDOW) {
      lastCheckNFCReaderTime = now;
      Serial.print("Check Reader Available\n\r");
      checkNFCReaderAvailable();
    }
  }

  if (laststate != machinestate) {
    Debug.printf("Changed from state <%s> to state <%s>\n",
                 state[laststate].label, state[machinestate].label);

    state[laststate].timeInState += (millis() - laststatechange) / 1000;
    laststate = machinestate;
    laststatechange = millis();
    return;
  }

  if (state[machinestate].maxTimeInMilliSeconds != NEVER &&
      ((millis() - laststatechange) > state[machinestate].maxTimeInMilliSeconds))
  {
    state[machinestate].timeoutTransitions++;

    laststate = machinestate;
    machinestate = state[machinestate].failStateOnTimeout;

    Log.printf("Time-out; transition from <%s> to <%s>\n",
               state[laststate].label, state[machinestate].label);
    return;
  };

  if (state[machinestate].autoReportCycle && \
      (millis() - laststatechange) > state[machinestate].autoReportCycle && \
      (millis() - lastReport) > state[machinestate].autoReportCycle)
  {
    Log.printf("State: %s now for %lu seconds", state[laststate].label, (millis() - laststatechange) / 1000);
    lastReport = millis();
  };

  // aartLed.set(state[machinestate].ledState);

  switch (machinestate) {
    case REBOOT:
      node.delayedReboot();
      break;

    case WAITINGFORCARD:
    case CHECKINGCARD:
      break;
    case CLEARSTATUS:
      machinestate = WAITINGFORCARD;
      break;
    case REJECTED:
      rejectedCards++;
      machinestate = WAITINGFORCARD;
      break;
    case APPROVED:
        openDoor();
        machinestate = LOCKOPEN;
      break;
    case LOCKOPEN:
      break;
    case LOCKCLOSED:
        checkNFCReaderAvailable();
        closeDoor();
        machinestate = WAITINGFORCARD;
      break;
    case BOOTING:
    case OUTOFORDER:
    case TRANSIENTERROR:
    case NOCONN:
      break;
  };
}

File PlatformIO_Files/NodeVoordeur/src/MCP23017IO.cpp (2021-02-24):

#include <Wire.h>
#include "MCP23017IO.h"
//#include "RFID.h"

Adafruit_MCP23017 mcp;

#define FET1_OUTPUT     11
#define FET2_OUTPUT     12
#define RELAY1_OUTPUT   8
#define RELAY2_OUTPUT   9

void setup_MCP23017() {
    Wire.begin(RFID_SDA_PIN, RFID_SCL_PIN, RFID_I2C_FREQ);
    mcp.begin(&Wire);
    mcp.pinMode(FET2_OUTPUT, OUTPUT);
    mcp.digitalWrite(FET2_OUTPUT, 0);
    mcp.pinMode(RELAY1_OUTPUT, OUTPUT);
    mcp.digitalWrite(RELAY1_OUTPUT, 0);

/* for test relay    
    delay(1000);
    mcp.digitalWrite(RELAY1_OUTPUT, 1);
    delay(1000);
    mcp.digitalWrite(RELAY1_OUTPUT, 0);
*/    

}

void openDoor() {
    mcp.digitalWrite(FET2_OUTPUT, 1);
}

void closeDoor() {
    mcp.digitalWrite(FET2_OUTPUT, 0);
}

void Relay1On() {
    mcp.digitalWrite(RELAY1_OUTPUT, 1);
}

void Relay1Off() {
    mcp.digitalWrite(RELAY1_OUTPUT, 0);
}

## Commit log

2021-02-18 Node voor voordeur, Versie 0.1.0.0, gebaseerd op nieuwe standaard node
    [NodeStandard-B_Cu.gbr, NodeStandard-B_Mask.gbr, NodeStandard-B_Paste.gbr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]
2021-02-24 V0.3.0.0 Addit workaround for problem with I2C cable to front door reader
    [MCP23017IO.cpp, main.cpp]
2021-02-24 Version 0.4.0.0: solved an issue with the recovery relay
    [MCP23017IO.cpp, main.cpp]
2021-02-24 V0.4.0.0, added the schematic drawing of the voordeurnode
    [NodeVoordeur.sch]
2021-02-24 V0.4.0.0, added the schematic drawing of the voordeurnode, now with the correct pdf of the drawing
2023-11-07 Based on Standard Node PCB V0.9
    [Clip ESP32 bovenkant.stl, Clip ESP32 onderkant.stl, Clip ESP32 v4.f3d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]
